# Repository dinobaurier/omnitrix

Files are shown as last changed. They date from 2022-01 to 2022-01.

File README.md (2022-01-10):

# Ben 10 inspired Omnitrix!



Using Pauls 3D things open smartwatch as a base, dfplayer mini for the sound, a lot of 3D printed parts and Eva Foam for the wrist.

See in action: https://youtu.be/jdq7B3sq1co

## Warning - this project is as far away from print in place as it gets. When it comes to the electronics, you should know what you do. No warranty from my side.

Files on Github
https://github.com/dinobaurier/omnitrix

The Smartwatch PCB
https://www.banggood.com/de/LILYGO-Pauls_3d_things-Open-Smartwatch-T-micro32-ESP32-WiFi-bluetooth-Circular-LCD-Module-p-1829416.html

DfPlayer mini for the sound (connect to pin 26(RX2) and 27(TX2) of the PCB) and a sd-card
https://de.aliexpress.com/item/32659631082.html

Speaker
https://de.aliexpress.com/item/1005001397625461.html

PowerButton 
https://www.pololu.com/product/2808 AND https://de.aliexpress.com/item/1005002533910294.html

Contacts used for the bezel and the "Open/Close" detection
The contacts are soldered to the pins of buttons 2 and 3 on the pcb.
The bezel contains 8 1.5x6mm steel bolts which connect the contacts. For open/close the contact is a soldered shortcut so if the upper side with the spring loaded contacts touches it, the button is triggered.
https://de.aliexpress.com/item/4000203259512.html

4 x 10x 3mm Neodym Magnets glued on the round elevations and opposing site - liked it more than springs. If I would start new, I'd try a design it with 6 magnets. 
https://de.aliexpress.com/item/1005002209122713.html

Contacts for the charger
https://de.aliexpress.com/item/1005001616656419.html

Charging board (the resistor must be changed in order to match the used battery)
https://de.aliexpress.com/item/1005001283272516.html

Battery used
https://eckstein-shop.de/LiPoAkkuLithium-IonPolymerBatterie32C7V350mAhJST-PHConnector

Watch Glas 38.5 x 1 mm

Halfrounds for decoration (10mm for the power button, 5mm for the bezel)
https://de.aliexpress.com/item/4000318763106.html

1 Crayola Green - I melted it and used it to fill the pattern underneath the bezel.

1 small nail, cut to connect the inside to the trigger.

EVA Foam
10mm grey
3mm black
1mm white - glue and roll

## Assembling
When assembling, keep the wires in the main body as short as possible as there is not much space to hide it afterwards.
For the cables which go outside (Power and Speaker) of the main body. use as thin as possible and flexible cables. otherwise it will have an effect on the pop up mechanism. 
I drilled a hole in the bottom cover to get the cables out. Also used some Hotglue to fix the necessary length for the movement inside the case.
Make sure to use some grease on the latch (Where it moves and on top) This makes opening and closing MUCH smoother. Depending on our print, you also have to sand a bit on the mechanism which holds the pop up part in order to make it smoother.

I used ASA for all the 3D printed parts.

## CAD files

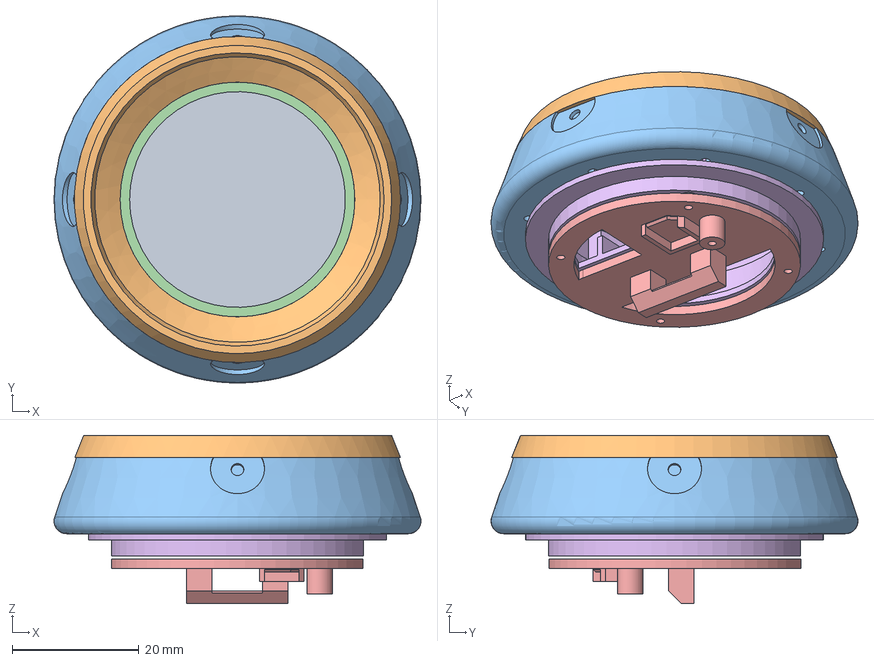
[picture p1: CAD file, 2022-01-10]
Step/Main Body.stp
57.8 x 57.8 x 26.5 mm
Glas
Aufsatzring
Drehkranz
Bezel Fixation
Oberteil Hebemechanismus

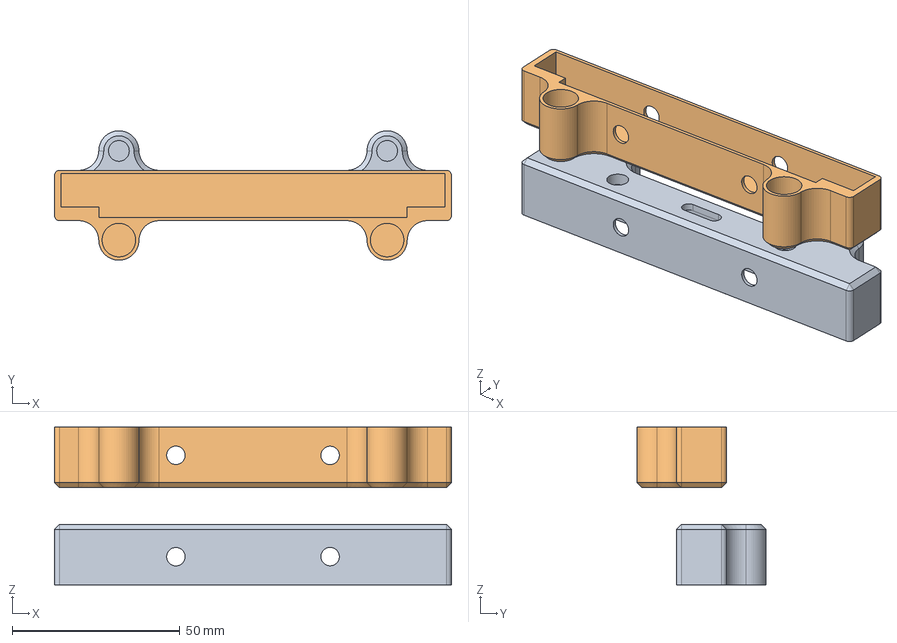
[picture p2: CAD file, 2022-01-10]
Step/Catch v6.step
118.4 x 38.6 x 47.0 mm

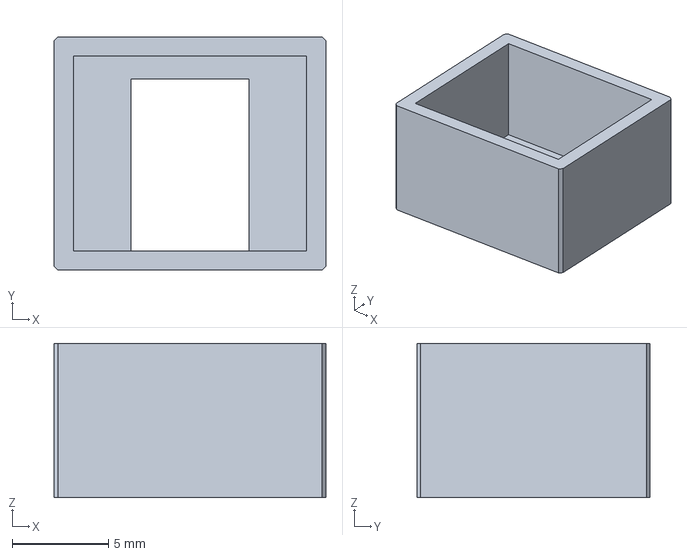
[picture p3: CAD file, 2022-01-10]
Step/Release Button Cover v8.step
14.1 x 12.1 x 8.00 mm

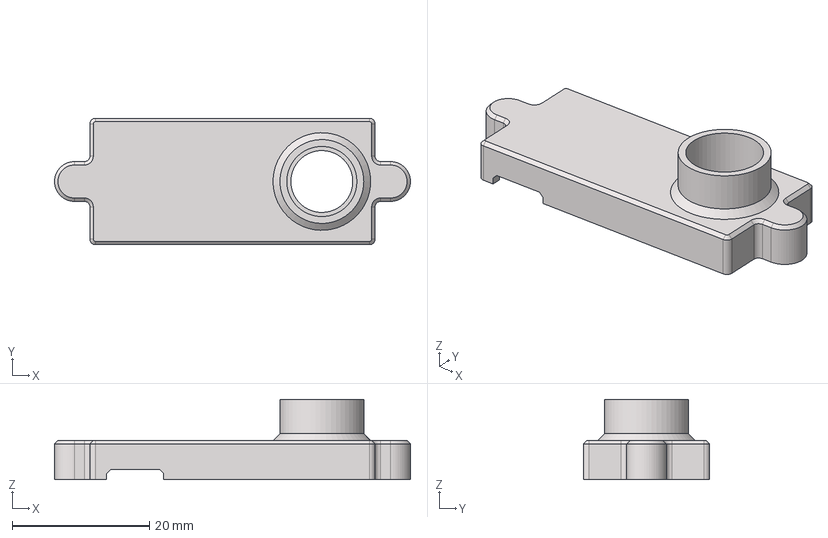
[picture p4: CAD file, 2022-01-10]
Step/Power Switch v4.step
51.8 x 18.4 x 11.7 mm

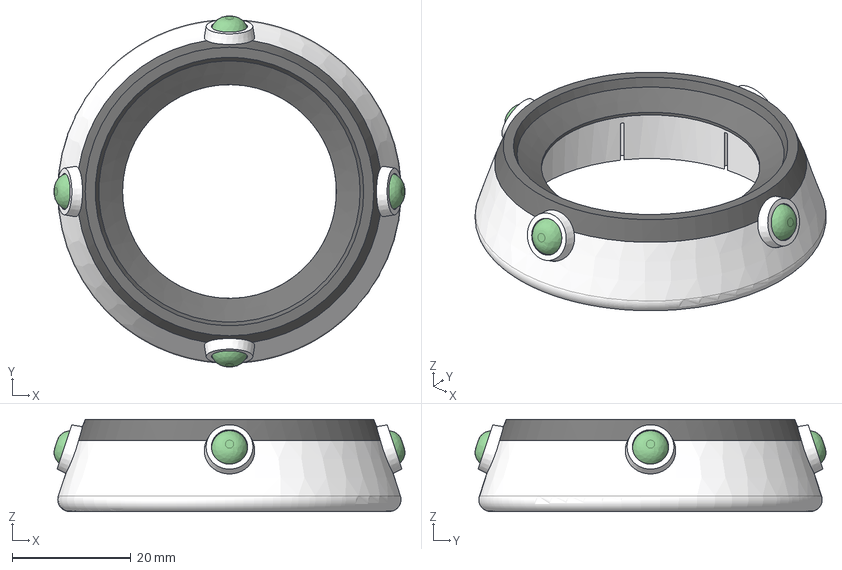
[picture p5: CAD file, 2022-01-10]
Step/Bezel v23.step
59.1 x 59.1 x 15.5 mm
IMlay Drehkranz x 4
Bezel Top Cover

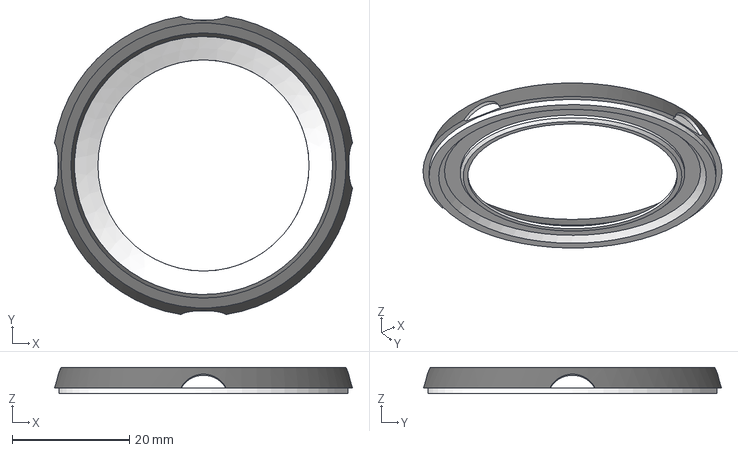
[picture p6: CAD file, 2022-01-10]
Step/Bezel Top Cover v21.step
50.8 x 50.8 x 4.50 mm

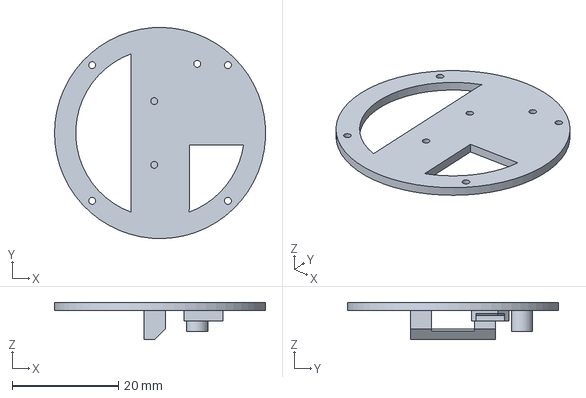
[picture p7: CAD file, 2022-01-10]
Step/Lift Top Spacer v42.step
39.7 x 39.7 x 7.00 mm

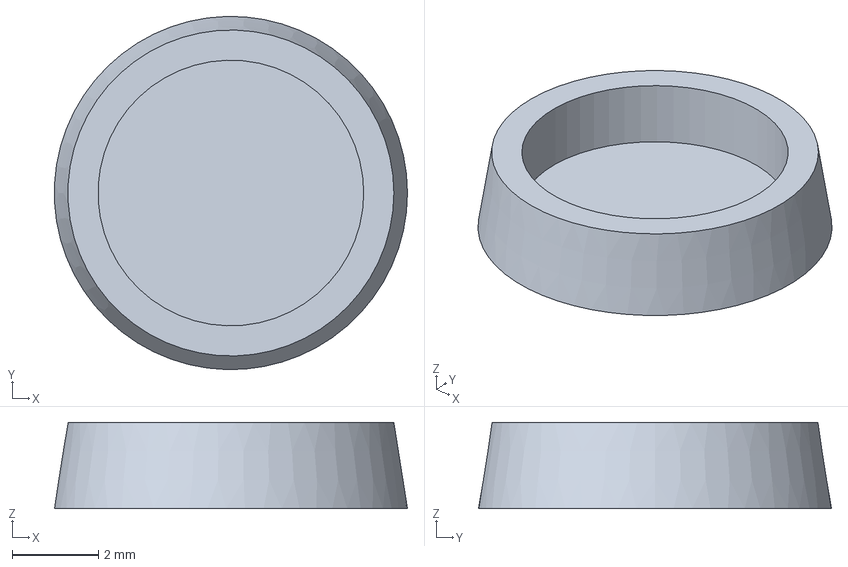
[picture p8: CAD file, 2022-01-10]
Step/Bezel Inlay v8.step
8.19 x 8.20 x 2.00 mm

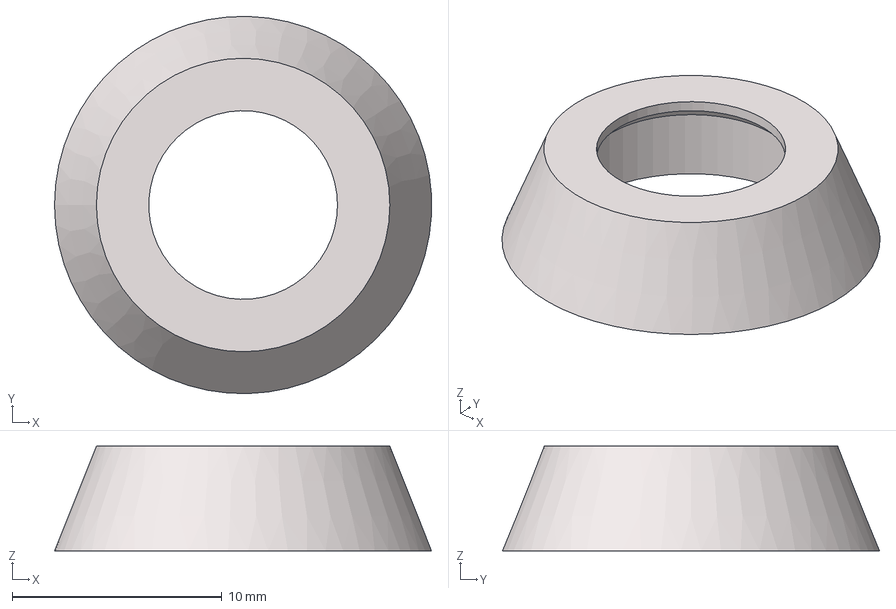
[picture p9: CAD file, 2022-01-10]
Step/Power Switch Top v6.step
18.0 x 18.0 x 5.00 mm

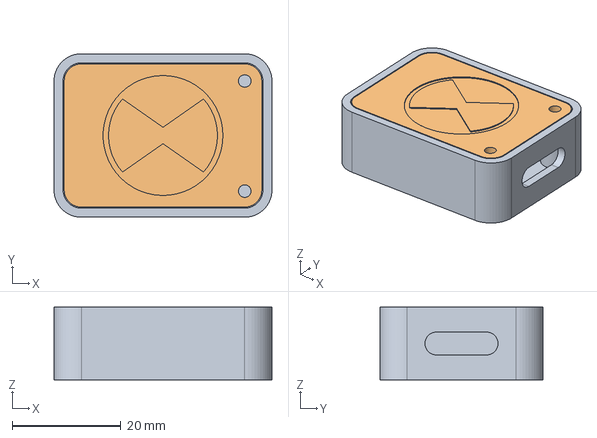
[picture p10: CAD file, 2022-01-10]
Step/Charger v2.step
40.0 x 30.0 x 13.3 mm

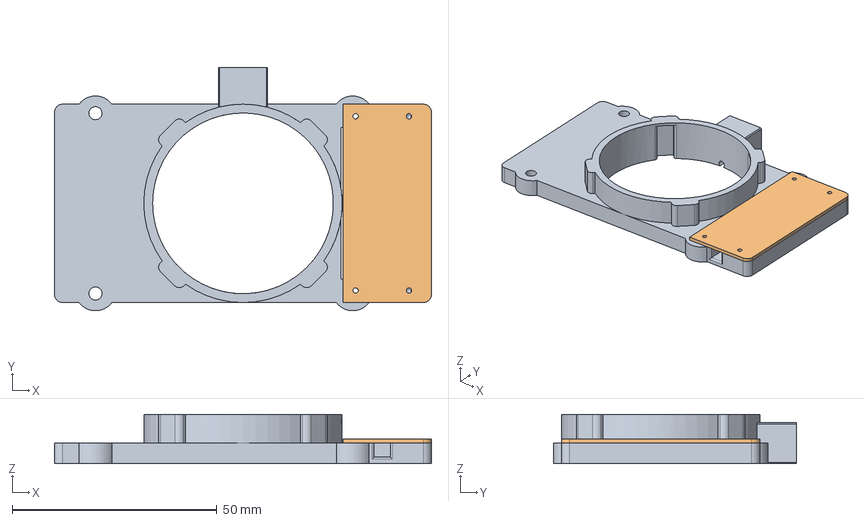
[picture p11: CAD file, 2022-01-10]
Step/Baseplate v47.step
92.0 x 59.4 x 12.0 mm

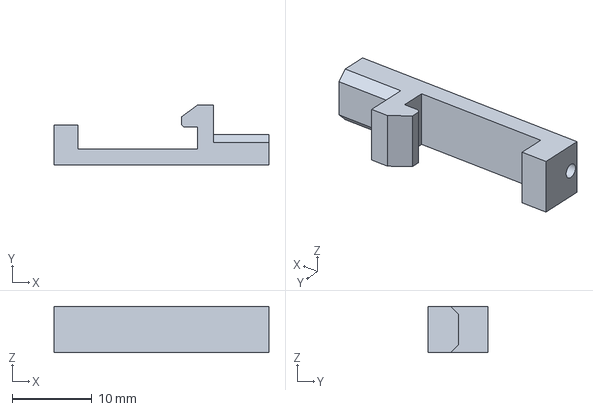
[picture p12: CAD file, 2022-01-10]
Step/Latch v14.step
27.0 x 7.50 x 5.80 mm

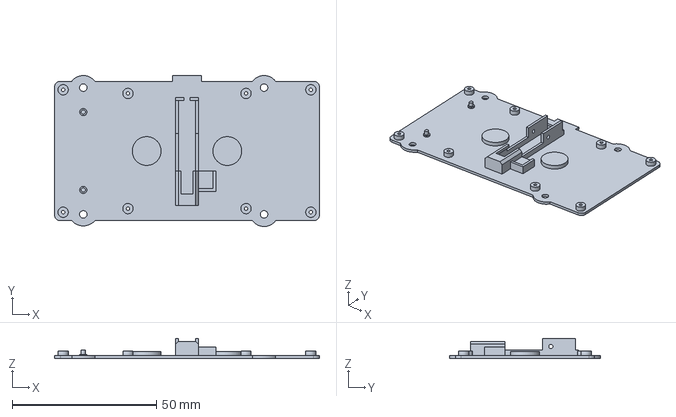
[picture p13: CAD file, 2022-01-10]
Step/Baseplate Cover v56.step
92.0 x 52.4 x 7.00 mm

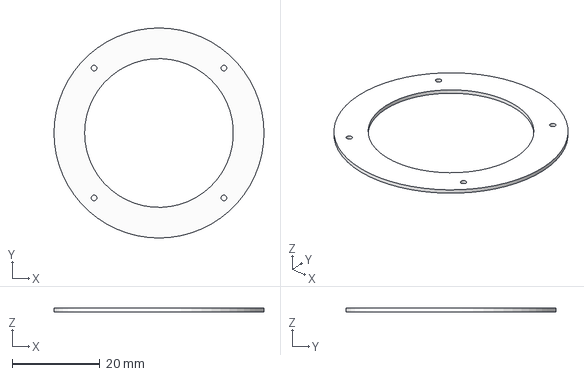
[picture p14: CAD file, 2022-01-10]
Step/Bezel Fixation v6.step
48.0 x 48.0 x 0.8 mm

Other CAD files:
Step/Lift Top v38.step
Step/Release Button v9.step
Step/Glas v1.step

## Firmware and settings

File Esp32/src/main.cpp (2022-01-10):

#include <Arduino.h>

#include <Arduino_GFX.h>
#include <Arduino_GC9A01.h>
#include <Arduino_ESP32SPI.h>
#include <Adafruit_I2CDevice.h>
#include <Adafruit_SPIDevice.h>

#include <SPIFFS.h>
#include <pngle.h>
#include "DFRobotDFPlayerMini.h"

#define GIF_FILENAME "/animation.gif"
#include "pins.h"


#include "GifClass.h"

const int pullUps[]={14,15,25,32,34,35,36,39};
static GifClass gifClass;

const int freq = 10000;
const int ledChannel = 13;
const int resolution = 8;

Arduino_DataBus *bus = new Arduino_ESP32SPI(TFT_DC, TFT_CS, TFT_SCK, TFT_MOSI, TFT_MISO, VSPI /* spi_num */);
Arduino_GC9A01 *gfx = new Arduino_GC9A01(bus, TFT_RST, 0 /* rotation */, true /* IPS */);

HardwareSerial myHardwareSerial(1); // use HardwareSerial UART1
DFRobotDFPlayerMini myDFPlayer;

// Parameter
const byte volume = 25, startSound = 1, nextSound = 3, selectSound = 4, endSound = 6, introSound = 8;
const int attacSeconds = 60; // Dauer Kampfmodus in Sekunden 
int transLoop = 0;
bool turn = false;
byte alienNo = 0, mode =1; // 1 = idle , 2 = alien Select , 3 = Kampf

int16_t xOffsetDefault = 65;
int16_t yOffsetDefault = 25;

int16_t xOffset = xOffsetDefault;
int16_t yOffset = yOffsetDefault;

#include "graphic.h"

// *************************************
// FUNTIONEN
// *************************************

void drawStart()
{
  gfx->fillScreen(DARKGREY);
  xOffset = 0;
  yOffset = 0;
  showImage(99);

  xOffset = xOffsetDefault;
  yOffset = yOffsetDefault;
}

void endTransformation()
{
  myDFPlayer.play(endSound);

  gfx->fillScreen(BLACK);
  delay(2000);
  // Offset ändern damit ganzer Bildschirm gefüllt wird.
  xOffset = 0;
  yOffset = 0;
  showImage(98);


  // und wieder auf Standard
  xOffset = xOffsetDefault;
  yOffset = yOffsetDefault;
}

void selectAlien(){
  if (alienNo == 11)  {
    // INTRO abspielen
    myDFPlayer.play(introSound);
  }
  else{
    myDFPlayer.play(selectSound);
  }
}

void nextAlien(){
  myDFPlayer.play(nextSound);
  alienNo++;
  if (alienNo == 12){
    alienNo = 1;
  }
  showImage(alienNo);
}

// *************************************
// FUNTIONEN ENDE 
// *************************************


void playStartAnimation(){
  myDFPlayer.play(startSound);
  File gifFile = SPIFFS.open(GIF_FILENAME, "r");

  if (!gifFile || gifFile.isDirectory()){
    // Serial.println(F("ERROR: open gifFile Failed!"));
    // gfx->println(F("ERROR: open gifFile Failed!"));
  }
  else{
    // read GIF file header
    gd_GIF *gif = gifClass.gd_open_gif(&gifFile);
    if (!gif){
      // Serial.println(F("gd_open_gif() failed!"));
    }
    else{
      int32_t s = gif->width * gif->height;
      uint8_t *buf = (uint8_t *)malloc(s);
      if (!buf){
        // Serial.println(F("buf malloc failed!"));
      }
      else{
        // Serial.println(F("GIF video start"));
        gfx->setAddrWindow((gfx->width() - gif->width) / 2, (gfx->height() - gif->height) / 2, gif->width, gif->height);
        int t_fstart, t_delay = 0, t_real_delay, res, delay_until;
        int duration = 0, remain = 0;
        while (1){
          t_fstart = millis();
          t_delay = gif->gce.delay * 10;
          res = gifClass.gd_get_frame(gif, buf);
          if (res < 0){
            // Serial.println(F("ERROR: gd_get_frame() failed!"));
            break;
          }
          else if (res == 0){
            // Serial.print(F("rewind, duration: "));
            // Serial.print(duration);
            // Serial.print(F(", remain: "));
            // Serial.print(remain);
            // Serial.print(F(" ("));
            // Serial.print(100.0 * remain / duration);
            // Serial.println(F("%)"));
            duration = 0;
            remain = 0;
            //gifClass.gd_rewind(gif);
            continue;
          }

          gfx->startWrite();
          gfx->writeIndexedPixels(buf, gif->palette->colors, s);
          gfx->endWrite();

          t_real_delay = t_delay - (millis() - t_fstart);
          duration += t_delay;
          remain += t_real_delay;
          delay_until = millis() + t_real_delay;
          do{
            delay(1);
          } while (millis() < delay_until);
        }
        // Serial.println(F("GIF video end"));
        // Serial.print(F("duration: "));
        // Serial.print(duration);
        // Serial.print(F(", remain: "));
        // Serial.print(remain);
        // Serial.print(F(" ("));
        // Serial.print(100.0 * remain / duration);
        // Serial.println(F("%)"));

        gifClass.gd_close_gif(gif);
        free(buf);
      }
    }
  }
}



void setup()
{

  // PULLUPS
  for (byte pin = 0; pin < sizeof(pullUps); pin++) {
    pinMode(pin, INPUT_PULLUP);
  }

  pinMode(TFT_LED, OUTPUT);
  // delay(1000);
  Serial2.begin(9600, SERIAL_8N1, RX2, TX2); // RX, TX
  Serial.begin(115200);

  ledcSetup(ledChannel, freq, resolution);
  ledcAttachPin(TFT_LED, ledChannel);
  ledcWrite(ledChannel, 255);

  // Serial.println();
  // Serial.println(F("DFRobot DFPlayer Mini Demo"));
  // Serial.println(F("Initializing DFPlayer ... (May take 3~5 seconds)"));
  //if (!myDFPlayer.begin(mySoftwareSerial)) {  //Use softwareSerial to communicate with mp3.
  myDFPlayer.setTimeOut(2000);

  if (!myDFPlayer.begin(Serial2, false)){ //Use HardwareSerial to communicate with mp3.
    // Serial.println(F("Unable to begin:"));
    // Serial.println(F("1.Please recheck the connection!"));
    // Serial.println(F("2.Please insert the SD card!"));
    while (true){
      delay(0); // Code to compatible with ESP8266 watch dog.
    }
  }
  // Serial.println(F("DFPlayer Mini online."));

  myDFPlayer.volume(volume); //Set volume value. From 0 to 30
  myDFPlayer.EQ(DFPLAYER_EQ_BASS);

  pinMode(BTN_RELEASE, INPUT);
  pinMode(BTN_RING, INPUT);

  // Init Display
  gfx->begin(40000000);
  gfx->fillScreen(DARKGREY);

/* Wio Terminal */
#if defined(ARDUINO_ARCH_SAMD) && defined(SEEED_GROVE_UI_WIRELESS)
  if (!SD.begin(SDCARD_SS_PIN, SDCARD_SPI, 4000000UL))
#elif defined(ESP32) || defined(ESP8266)
  if (!SPIFFS.begin())
  // if (!SD.begin())
#else
  if (!SD.begin())
#endif
  {
    // Serial.println(F("ERROR: File System Mount Failed!"));
    // gfx->println(F("ERROR: File System Mount Failed!"));
  }

  drawStart();
}

void loop(){

  // Startmodus - es wird nur auf Öffnung der Omnitrix reagiert
  if (mode == 1){
    int Button_RELEASE_state = digitalRead(BTN_RELEASE);
    if (Button_RELEASE_state == LOW){
      delay(200);
      mode = 2;
      playStartAnimation();
    }
  }

  // Auswahlmodus - reagiert auf Drehring und Reindrücken
  else if (mode == 2){
    int Button_RING_state = digitalRead(BTN_RING);
    int Button_RELEASE_state = digitalRead(BTN_RELEASE);

    // Drehring hat den Kontakt berührt
    if (Button_RING_state == HIGH && turn == false){
      turn = true;
    }

     // Wechsel erst ausführen wenn Kontakt am Drehring wieder weg ist
    else if (Button_RING_state == LOW && turn == 1){
      turn = false;
      nextAlien();
    }

    // Herabgedrückt - Alien ausgewählt. 
    if (Button_RELEASE_state == HIGH){
      delay(200);
      if (alienNo > 0){
        mode = 3;
        // Serial.println(F("Alien Selected"));
        selectAlien();
      }
      // Wenn kein Alien ausgewählt, wieder auf Start
      else{
        mode = 1;
        drawStart();
      }
    }
  }

  // Kampfmodus
  else if (mode == 3){
    transLoop++;
    delay(500);

    int Button_RELEASE_state = digitalRead(BTN_RELEASE);

    // Wenn wieder geöffnet wird, Kampfmodus abbrechen
    if (Button_RELEASE_state == LOW){
      mode = 2;
      transLoop = 0;
      playStartAnimation();
    }

    // Nach Dauer attacSeconds wieder zurück in Startmodus wechseln
    if (transLoop > attacSeconds * 2){
      transLoop = 0;
      mode = 1;
      endTransformation();
    }
  }
}
